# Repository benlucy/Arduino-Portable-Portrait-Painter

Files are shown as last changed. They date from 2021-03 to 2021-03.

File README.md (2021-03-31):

# Arduino-Portable-Portrait-Painter
Code to run Arduino based portable portrait painter

Mechanical Build on Instructables.com (coming soon)

Working machine: https://www.youtube.com/watch?v=U5dt6qbI_Uw 

-------------------------------------------------------------------------------  
  
Compiling in Arduino IDE:  
  
1. Download all files
2. Copy "src/lib/LiveOV7670Library" and "src/lib/Adafruit_GFX_Library" to Arduino "libraries" folder (If you already have "Adafruit_GFX_Library" then you don't have to copy that)
3. Open "src/LiveOV7670/LiveOV7670.ino" in Arduino IDE
4. Select Tools->Board->Arduino/Genuino Mega or Mega 2560
5. Select Tools->Processor->ATmega2560 (Mega 2560)
  
-------------------------------------------------------------------------------

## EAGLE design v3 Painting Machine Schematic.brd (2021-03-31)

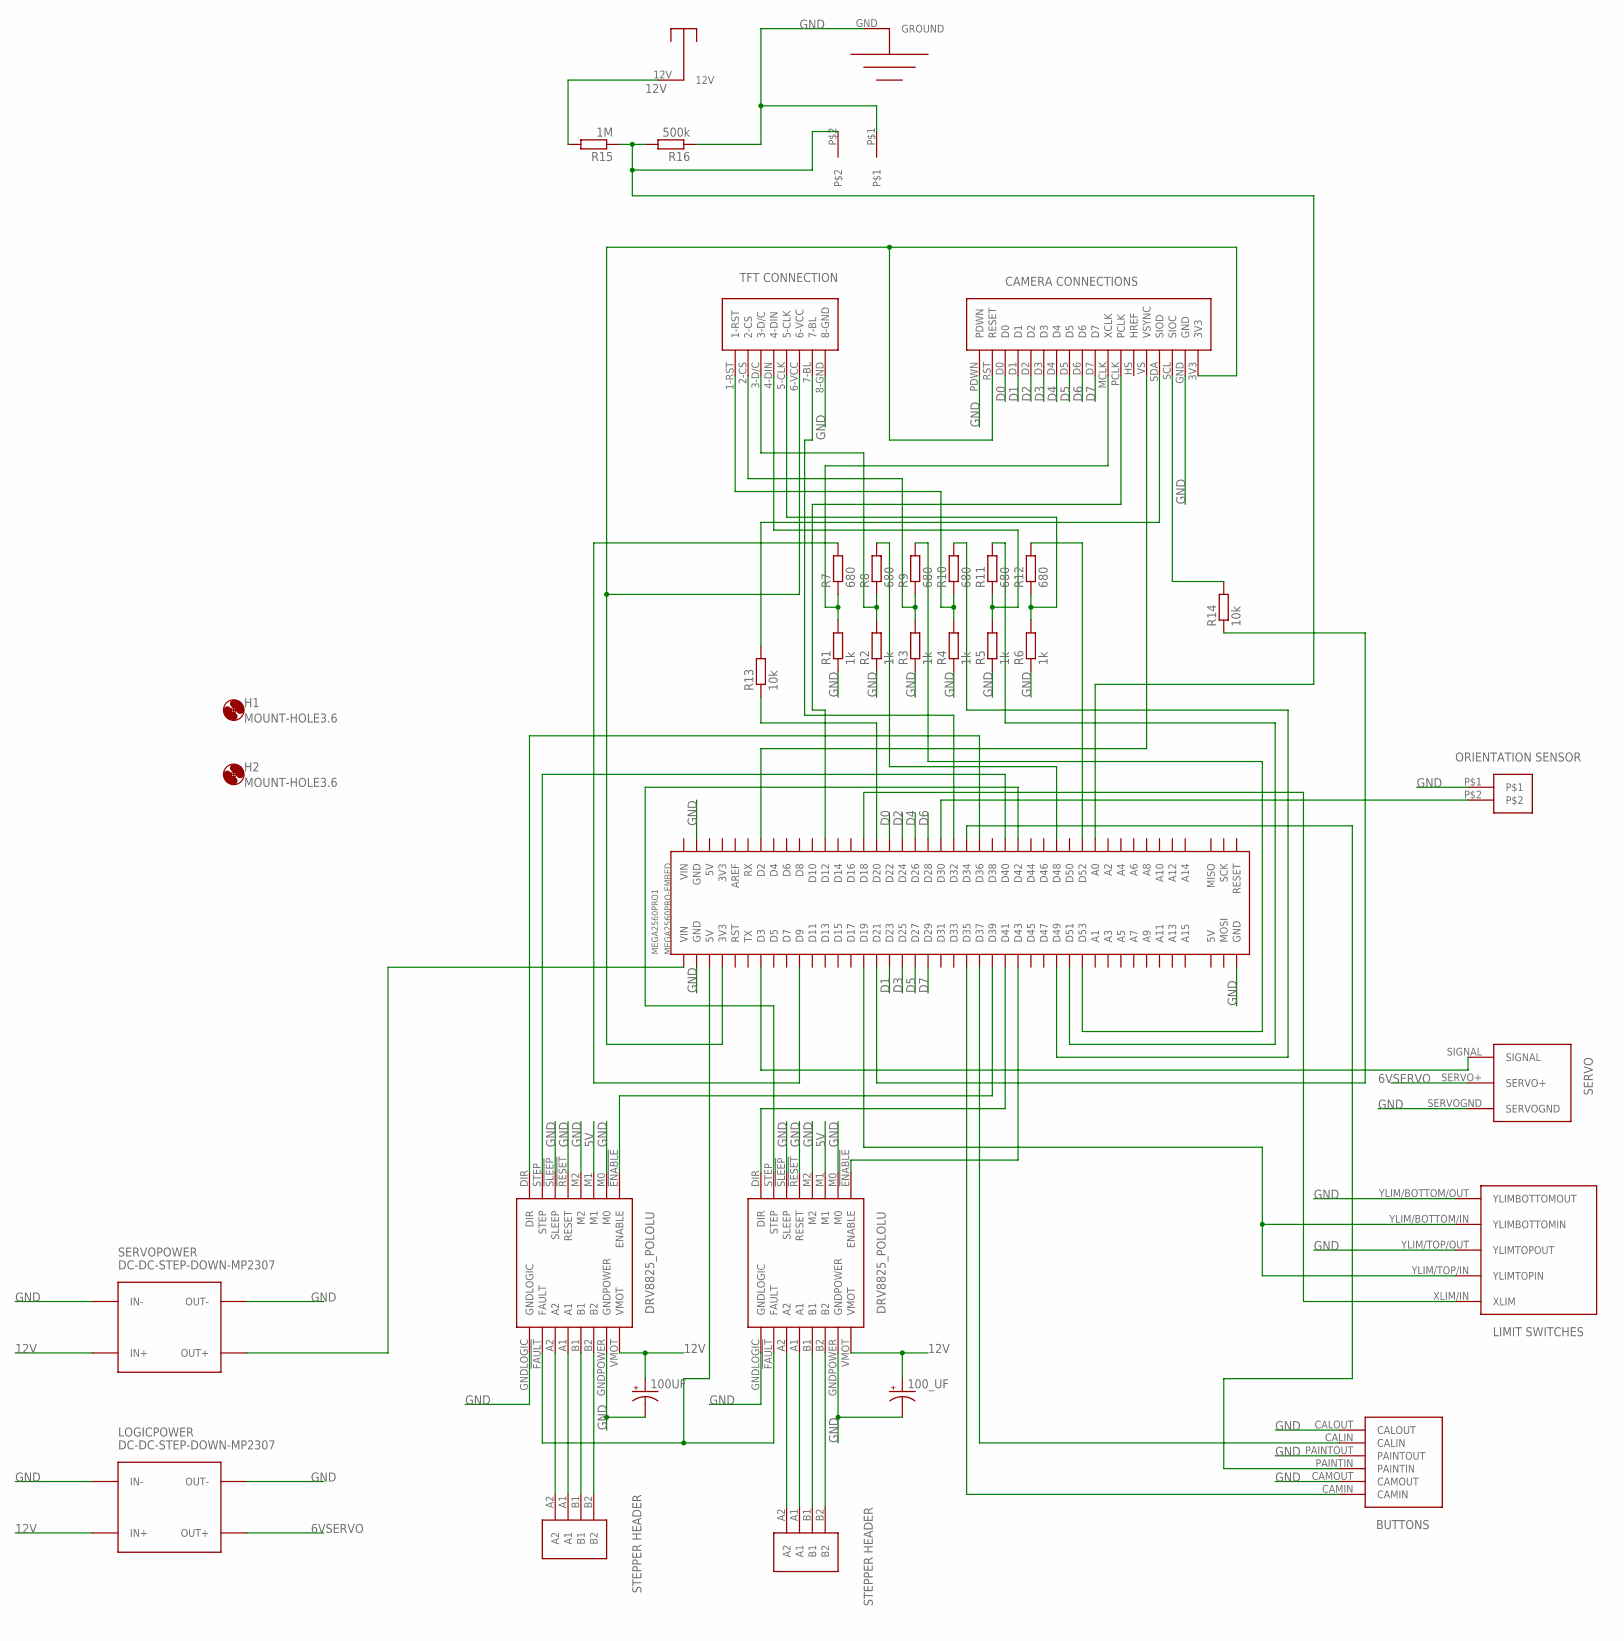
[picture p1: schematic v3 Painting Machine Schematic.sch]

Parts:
100UF, 100_UF: CPOL-USB45181B; B45181B
H1, H2: MOUNT-HOLE3.6; 3,6
LOGICPOWER: DC-DC-STEP-DOWN-MP2307
MEGA2560PRO1: MEGA2560PRO-EMBED
R1, R2, R3, R4, R5, R6: 1k; 0207/7
R7, R8, R9, R10, R11, R12: 680; 0207/7
R13, R14: 10k; 0207/7
R15: 1M; 0207/7
R16: 500k; 0207/7
SERVOPOWER: DC-DC-STEP-DOWN-MP2307
U$1, U$2: DRV8825_POLOLU_CARRIER; DRV8825_POLOLU
U$4: TFT/CONNECTIONS; TFTCONNECTIONS
U$5: OV7670CONNECTIONS; CAMERACONNECTIONS
U$6: ORIENTATIONSENSOR
U$7: 12V; VCC
U$8: GROUND
U$9, U$10: STEPPER_HEADER
U$11: SERVO
U$12: LIMITSWITCHES
U$13: BUTTONS; INPUTBUTTONS
U$14: CERAMICCAPACITOR

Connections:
5V: U$1.M1, U$2.M1
6VSERVO: LOGICPOWER.OUT+, U$11.SERVO+
12V: 100UF.+, 100_UF.+, LOGICPOWER.IN+, R15.2, SERVOPOWER.IN+, U$1.VMOT, U$2.VMOT, U$7.12V
D0: MEGA2560PRO1.D22, U$5.D0
D1: MEGA2560PRO1.D23, U$5.D1
D2: MEGA2560PRO1.D24, U$5.D2
D3: MEGA2560PRO1.D25, U$5.D3
D4: MEGA2560PRO1.D26, U$5.D4
D5: MEGA2560PRO1.D27, U$5.D5
D6: MEGA2560PRO1.D28, U$5.D6
D7: MEGA2560PRO1.D29, U$5.D7
GND: 100UF.-, 100_UF.-, LOGICPOWER.IN-, LOGICPOWER.OUT-, MEGA2560PRO1.GND@1 (GND), MEGA2560PRO1.GND@2 (GND), MEGA2560PRO1.GND@3 (GND), R1.1, R2.1, R3.1, R4.1, R5.1, R6.1, R16.1, SERVOPOWER.IN-, SERVOPOWER.OUT-, U$1.!RESET (RESET), U$1.!SLEEP (SLEEP), U$1.GNDLOGIC, U$1.GNDPOWER, U$1.M0, U$1.M2, U$2.!RESET (RESET), U$2.!SLEEP (SLEEP), U$2.GNDLOGIC, U$2.GNDPOWER, U$2.M0, U$2.M2, U$4.8-GND, U$5.GND, U$5.PDWN, U$6.P$1, U$8.GND, U$11.SERVOGND, U$12.YLIM/BOTTOM/OUT (YLIMBOTTOMOUT), U$12.YLIM/TOP/OUT (YLIMTOPOUT), U$13.CALOUT, U$13.CAMOUT, U$13.PAINTOUT, U$14.P$1
unnamed: U$2.A2, U$9.A2
unnamed: U$2.A1, U$9.A1
unnamed: U$2.B1, U$9.B1
unnamed: U$2.B2, U$9.B2
unnamed: U$1.A2, U$10.A2
unnamed: U$1.A1, U$10.A1
unnamed: U$1.B1, U$10.B1
unnamed: U$1.B2, U$10.B2
unnamed: MEGA2560PRO1.D9, R7.2
unnamed: MEGA2560PRO1.D48, R8.2
unnamed: MEGA2560PRO1.D53, R9.2
unnamed: MEGA2560PRO1.D49, R10.2
unnamed: R5.2, R11.1, U$4.4-DIN
unnamed: R6.2, R12.1, U$4.5-CLK
unnamed: MEGA2560PRO1.D12, U$5.PCLK
unnamed: MEGA2560PRO1.D52, R12.2
unnamed: MEGA2560PRO1.D51, R11.2
unnamed: R4.2, R10.1, U$4.1-RST
unnamed: R3.2, R9.1, U$4.2-CS
unnamed: R2.2, R8.1, U$4.3-D/C
unnamed: MEGA2560PRO1.D20, R13.1
unnamed: R1.2, R7.1, U$5.MCLK (XCLK)
unnamed: R13.2, U$5.SDA (SIOD)
unnamed: MEGA2560PRO1.D21, R14.1
unnamed: R14.2, U$5.SCL (SIOC)
unnamed: MEGA2560PRO1.3V3@1 (3V3), U$4.6-VCC, U$5.3V3, U$5.RST (RESET)
unnamed: MEGA2560PRO1.D2, U$5.VS (VSYNC)
unnamed: MEGA2560PRO1.D3, U$11.SIGNAL
unnamed: MEGA2560PRO1.D30, U$6.P$2
unnamed: MEGA2560PRO1.D19, U$12.YLIM/BOTTOM/IN (YLIMBOTTOMIN), U$12.YLIM/TOP/IN (YLIMTOPIN)
unnamed: MEGA2560PRO1.D18, U$12.XLIM/IN (XLIM)
unnamed: MEGA2560PRO1.D35, U$13.CAMIN
unnamed: MEGA2560PRO1.D37, U$13.CALIN
unnamed: MEGA2560PRO1.D34, U$13.PAINTIN
unnamed: MEGA2560PRO1.D41, U$1.DIR
unnamed: MEGA2560PRO1.D43, U$1.!ENABLE (ENABLE)
unnamed: MEGA2560PRO1.D39, U$2.!ENABLE (ENABLE)
unnamed: MEGA2560PRO1.D42, U$1.STEP
unnamed: MEGA2560PRO1.D40, U$2.STEP
unnamed: MEGA2560PRO1.D36, U$2.DIR
unnamed: MEGA2560PRO1.5V@1 (5V), U$1.!FAULT (FAULT), U$2.!FAULT (FAULT)
unnamed: MEGA2560PRO1.D32, U$4.7-BL
unnamed: MEGA2560PRO1.A0, R15.1, R16.2, U$14.P$2
VIN: MEGA2560PRO1.VIN@1 (VIN), SERVOPOWER.OUT+

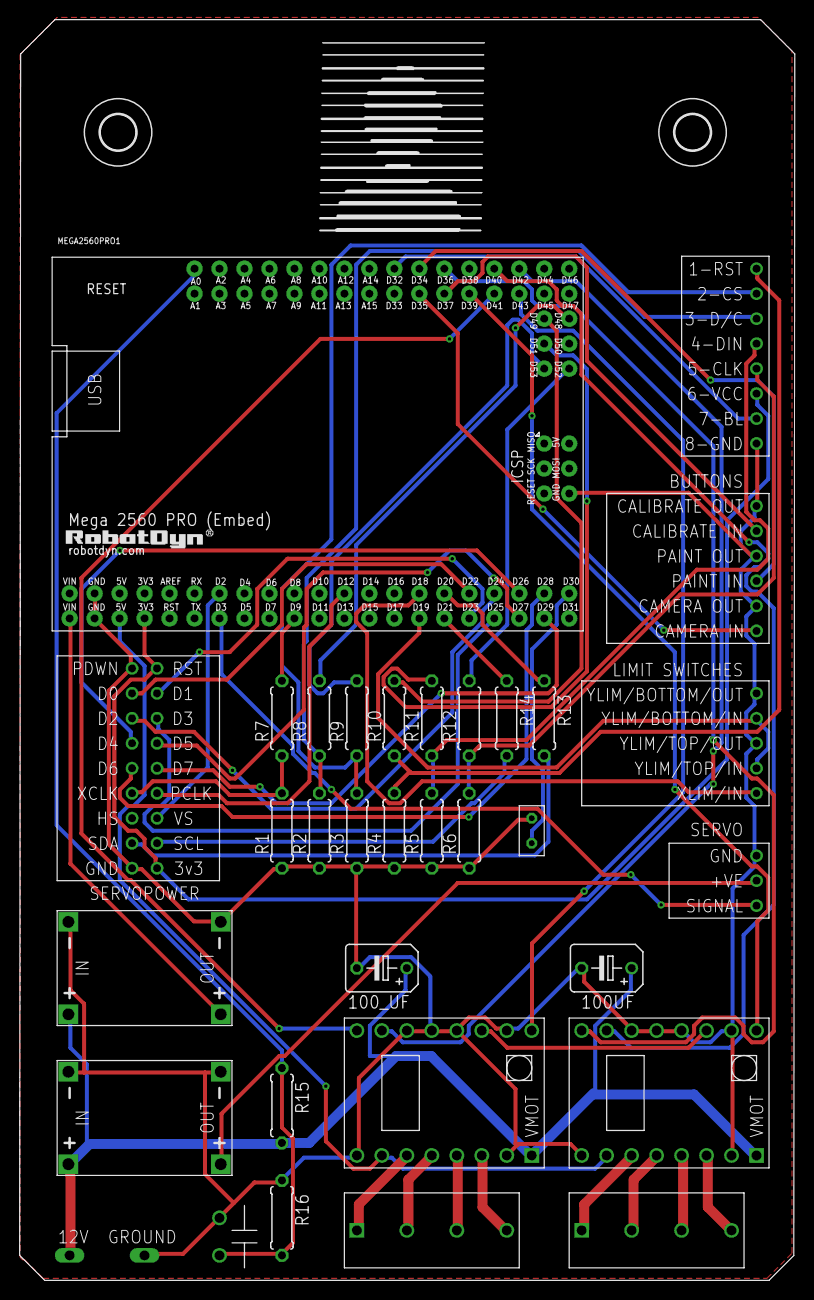
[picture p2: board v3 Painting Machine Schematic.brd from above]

Board: 2 copper layers, 78.8 x 128.2 mm, 36 parts (0 on the bottom side), 56 nets.

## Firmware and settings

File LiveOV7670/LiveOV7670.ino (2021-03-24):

//This code originally created by Indrek Luuk to display OV7670 video on a TFT screen.
//Modified by @SouravSh25 on 22.09.2020 to include a readGRAM  function, to read pixel data from the screen.
//Modified by Ben Lucy, to control a portable portait painting machine 18/12/2020.
//Code in this tab written by Ben Lucy, very minor edits have been made to the other tabs of Indrek's code e.g. edited variables to mirror the image.

// change setup.h to switch between buffered and pixel-by-pixel processing
#include "setup.h"
#include "Adafruit_ST7735_mod.h"
#include "readGRAM.h"
extern Adafruit_ST7735_mod tft;

#include <AccelStepper.h>
#include <Servo.h>


//declare all arduino pins inputs outputs

//TMC2208 stepper motor driver pins
#define RightStepperSTEP 40
#define RightStepperDIR 36
#define RightStepperENABLE 39

#define LeftStepperSTEP 42
#define LeftStepperDIR 41
#define LeftStepperENABLE 43

//limit switch inputs
#define Xlim 18
#define Ylim 19

//buttons
#define CalibrateButton 37
#define PaintButton 34
#define CameraButton 35

//other
#define ServoSignalPin 3
#define BatteryMonitor A0
#define OrientationSensor 30
#define BackLight 32


//define global variables
#define ZeroingSpeed 600
#define ServoMinHeight 158
#define ServoMaxHeight 30
#define ServoStartPosition 94
#define MinInterval 210 //(large = lower max speed. Too fast affects acceleration (crudely coded acc), causing skipped steps)
#define IntervalChange 100 //larger = faster acceleration which may cause skipped steps
int StepsTotal;
unsigned int CurrentTime;
unsigned int SavedTime;
int interval = MinInterval;
int TargetInterval = interval;
unsigned long previousMicros = 0;
byte StepPins = 0;
int MinContactHeight;
int MaxBrushPress = 22;
float ServoPos = 90;
int RowCounter = 0;
bool RunCamera = true;
float BrushArray[165];
float PixelValueFrequency[256];
float PixelValueCumulativeFrequency[256];
float PixelLookUpTable[256];
extern uint32_t GRAM_buffer[165]; //GRAM-buffer is declared in another tab, but I need it to have global scope to work here. 'Extern' makes it a data declaration, not a data definition.

//create instances for the AccelStepper class & Servo class:
AccelStepper LeftStepper = AccelStepper(1, LeftStepperSTEP, LeftStepperDIR);
AccelStepper RightStepper = AccelStepper(1, RightStepperSTEP, RightStepperDIR);
Servo BrushServo;

//conversion for brush change (degrees) to stepper interval (us) to travel at a speed that allows brush to change position within 1mm travel (1 pixel). Calculated via: 1000000(convert units to us)/ 25(no.steps)*300(deg/sec servo speed)*brush change(deg). Or: 1000000/(25*300*DegChange). Or: 66.7* DegChange

//if brush changes by 0 degree between one pixel and the next, stepper interval should be MinIntervalus (max speed). 3deg = 200us.
//interval is time between step pin changing state, so one step takes 2 intervals
//(1deg/2deg/3deg...etc
//{MinInterval, MinInterval, MinInterval, 200, 267, 333, 400, 467, 533, 600, 667, 733, 800, 867, 933, 1000, 1067, 1135, 1200, 1267, 1353, 1400, 1467};


void setup() {

  BrushServo.attach(ServoSignalPin);
  BrushServo.write(ServoPos);
  LeftStepper.setMaxSpeed(4000); //15000
  LeftStepper.setAcceleration(100000);
  BrushServo.attach(ServoSignalPin);
  BrushServo.write(ServoPos);
  RightStepper.setMaxSpeed(4000);
  RightStepper.setAcceleration(100000); //250000

  pinMode(BatteryMonitor, INPUT);
  pinMode(OrientationSensor, INPUT);


  pinMode(Xlim, INPUT_PULLUP);
  pinMode(Ylim, INPUT_PULLUP);

  pinMode(CalibrateButton, INPUT_PULLUP);
  pinMode(PaintButton, INPUT_PULLUP);
  pinMode(CameraButton, INPUT_PULLUP);

  pinMode(RightStepperENABLE, OUTPUT);
  pinMode(LeftStepperENABLE, OUTPUT);

  digitalWrite(LeftStepperENABLE, 1);
  digitalWrite(RightStepperENABLE, 1);
  
  BrushServo.detach();
  initializeScreenAndCamera();
  //  Serial.begin(9600);

  TIMSK0 = 0;



  //display battery voltage on start-up
  //fill screen to show battery charge condition
  digitalWrite(BackLight, 1);
  switch (analogRead(BatteryMonitor)) {
    case 0 ... 749:                       // <11.0V
      tft.fillScreen(ST7735_RED);
      break;
    case 750 ... 790:                     // 11.0 - 11.6V
      tft.fillScreen(ST7735_YELLOW);
      break;
    case 791 ... 1023:                    // >11.6V
      tft.fillScreen(ST7735_GREEN);
      break;
  }
  TIMSK0 = 1;
  delay(1000);
  tft.fillScreen(ST7735_BLACK);
  TIMSK0 = 0;

}

void loop() {

  tft.setRotation(2); //sets the screen the right way up. The values in Indrek's code have been edited so that the image shown is mirrored.

  //If CameraButton is pressed, start or stop the camera.
  if (RunCamera == true) processFrame(); // runs camera

  if (digitalRead(CameraButton) == LOW) {
    if (RunCamera == true) {
      RunCamera = false;                        //freezes camera/screen
      TIMSK0 = 1;                               //enable timer0 which enables delay() function (and millis function for elsewhere in the code).
      delay(500);                               //button debounce / long press prevention
    }
    else {
      RunCamera = true;                         //resumes camera
      delay(500);                               //button debounce / long press prevention
      TIMSK0 = 0;                               //disables timer0 which removes artifacts from the screen
    }
  }



  //If calibrate button is pressed:
  //Axes are zeroed.
  //Gantry starts drawing lines while the brush moves lower and lower.
  //When the brush makes contact with the page and starts drawing a line, the user should press calibrate again.
  //The system will save the MinimumContactHeight of the servo (servo position when calibrate was pressed 2nd time).
  //The system will stop drawing lines and re-zero the axes.

  if (digitalRead(CalibrateButton) == LOW) {
    digitalWrite(LeftStepperENABLE, 0);
    digitalWrite(RightStepperENABLE, 0);
    RunCamera = false;
    TIMSK0 = 1;
    BrushServo.attach(ServoSignalPin);
    BrushServo.write(ServoPos - 25);
    ZeroAxes();
    CalibrateRoutine();
    BrushServo.detach();
    digitalWrite(LeftStepperENABLE, 1);
    digitalWrite(RightStepperENABLE, 1);
  }


  //If paint button is pressed:
  //Axes are zeroed
  //Brush moves up to start position
  // (a) Image processing happens
  // (b) 128 pixels are read from the screen
  // (c) 128 pixels are painted and the brush moves to the next row position
  // a & b repeat for 80 rows
  //the brush is lifted
  //the axes are zeroed.


  if (digitalRead(PaintButton) == LOW) {  //paint the image currently frozen on the screen.
    digitalWrite(LeftStepperENABLE, 0);
    digitalWrite(RightStepperENABLE, 0);

    RunCamera = false;
    TIMSK0 = 1;
    BrushServo.attach(ServoSignalPin);

    ZeroAxes();

    //move up 1375 steps (55mm)
    LeftStepper.move(1375);
    RightStepper.move(-1375);
    while (LeftStepper.currentPosition() != 1375) {
      LeftStepper.run();
      RightStepper.run();
    }

    ImageProcessing();

    RowCounter = 3;  //first few rows of pixels might be nothing? Maybe they're not actual pixels and just exist in the screen register?? Maybe they are legit pixels but I can't bother to upload and verify.
    while (RowCounter < 160) {

      //read the screen GRAM
      initiate_readGRAM();
      readGRAM_Row(GRAM_buffer, RowCounter);


      //converts the pixel array into brush positions. //Using data-type 'byte' for PixelLookUpTable might shorten the pause before painting each line.
      for (int i = 0; i < 128; i++) {
        GRAM_buffer[i] = GRAM_buffer[i] << 16;                                    //GRAM_buffer contains 32bit numbers. The first 8x bits are zero. The next 3 bytes are similar (because RGB/greyscale). G has the most info because RGB565, so use G byte. Outputs number from 0-255 after <<16 & >>24.
        GRAM_buffer[i] = GRAM_buffer[i] >> 24;
        GRAM_buffer[i] = PixelLookUpTable[GRAM_buffer[i]]; //Am I getting away with putting float into long here??  ??  //Revises the pixels according to Histogram Equalisation. E.g. the 5th pixel has a value 106 (GRAM_buffer[5] == 106). The 106th element of the PixelLookUpTable is 122, so the fifth pixel is updated with this value (GRAM_buffer[5]=122).
        BrushArray[i] = (float)GRAM_buffer[i];                                    //cast to float array
        BrushArray[i] = MinContactHeight + MaxBrushPress - (BrushArray[i] * (MaxBrushPress / 255.0));    //Scales BrushArray into servo-range friendly values. Weird formula is because BrushArray seems to be inverted.
      }

      Paint128Pixels();
      ReadyForNextRow();
      RowCounter = RowCounter + 2;
    }
    BrushServo.write(ServoPos - 35);
    delay(250);
    ZeroAxes();
    BrushServo.detach();
    digitalWrite(LeftStepperENABLE, 1);
    digitalWrite(RightStepperENABLE, 1);
    initializeScreenAndCamera();
  }
}

//function to zero axes at the bottom left corner
void ZeroAxes() {

  while (digitalRead(Xlim) == HIGH) {
    LeftStepper.setSpeed(-1 * ZeroingSpeed);
    RightStepper.setSpeed(-1 * ZeroingSpeed);
    LeftStepper.runSpeed();
    RightStepper.runSpeed();
  }

  while (digitalRead(Ylim) == HIGH) {
    LeftStepper.setSpeed(-1 * ZeroingSpeed);
    RightStepper.setSpeed(ZeroingSpeed);
    LeftStepper.runSpeed();
    RightStepper.runSpeed();
  }

  LeftStepper.setCurrentPosition(0);
  RightStepper.setCurrentPosition(0);

  //moves 4mm right and 4mm up.
  while (LeftStepper.currentPosition() != 200)
  {
    LeftStepper.setSpeed(ZeroingSpeed);
    LeftStepper.runSpeed();
  }
  LeftStepper.setCurrentPosition(0);
  RightStepper.setCurrentPosition(0);

  //move the servomotor down a little to stop it making noise
  BrushServo.write(ServoPos + 1);
  delay(200);
  BrushServo.write(ServoPos + 1);
  delay(200);
  BrushServo.write(ServoPos + 1);
}

void CalibrateRoutine() {

  //run the stepper motors in an 80 line pattern
  int LinesDrawn = 0;
  int CalibrateState = 1;
  while (LinesDrawn != 80 && CalibrateState == 1) {

    BrushServo.write(ServoPos);

    //move right 128mm (3200 steps)
    LeftStepper.move(3200);
    RightStepper.move(3200);
    while (LeftStepper.distanceToGo() != 0 && digitalRead(CalibrateButton) == HIGH) {
      LeftStepper.run();
      RightStepper.run();
    }

    BrushServo.write(ServoPos - 35);

    //move up 2mm (50steps)
    LeftStepper.move(50);
    RightStepper.move(-50);
    while (LeftStepper.distanceToGo() != 0 && digitalRead(CalibrateButton) == HIGH) {
      LeftStepper.run();
      RightStepper.run();
    }

    //move left 130mm (3200)
    LeftStepper.move(-3200);
    RightStepper.move(-3200);
    while (LeftStepper.distanceToGo() != 0 && digitalRead(CalibrateButton) == HIGH) {
      LeftStepper.run();
      RightStepper.run();
    }

    if (digitalRead(CalibrateButton) == LOW) {
      CalibrateState = 2;
      MinContactHeight = ServoPos;
      ServoPos = 90;
      BrushServo.write(ServoPos - 25);
      delay(250);
      ZeroAxes();
    }

    LinesDrawn = LinesDrawn + 1;
    ServoPos = ServoPos + 1;

  }
}

void Paint128Pixels() {

  digitalWrite(LeftStepperDIR, 1);
  digitalWrite(RightStepperDIR, 1);

  StepsTotal = 0;
  previousMicros = 0;
  char CurrentPixel = 0;
  char PreviousPixel = 0;
  char BrushChange;
  char PixelStepsTotal = 0;
  long microsAfter;
  long microsBefore;

  while (StepsTotal < 6400) {                                             //64000 = half steps. 25 full steps is 1mm

    //************************************************
    //every pixel (50) check difference in brush position between current and next pixel in GRAM_buffer[]
    //update stepper interval variable according to brush movement distance

    if (PixelStepsTotal >= 50) {                                           //executes every pixel (50 half-steps). (Used to use modulo for this but strange things happened)
      PixelStepsTotal = 0;
      PreviousPixel = CurrentPixel;                                           //indicates which pixel we were on (0 - 127)
      CurrentPixel = CurrentPixel + 1;                                        //indicates which pixel we are currently on (0 - 127)
      BrushChange = BrushArray[PreviousPixel] - BrushArray[CurrentPixel];       //difference between current and previous brush position is the distance the brush must move (in degrees)
      BrushChange = abs(BrushChange);
      if (BrushChange >= 3) TargetInterval = 67 * BrushChange;                      //66.7 converts servo position degree change to an interval controlling the speed the steppers should be going to allow the brush to change position within the width of 1 pixel. Line ~71 comment
      else TargetInterval = MinInterval;
      BrushServo.write(BrushArray[CurrentPixel]);

      if (digitalRead(PaintButton) == LOW) {   //Press paint button again to cancel painting
        StepsTotal = 6401;                     //Exits while loop
        RowCounter = 161;                      //Exits back to loop()
        ServoPos = 90;
        BrushServo.write(ServoPos - 35);
        delay(250);
        ZeroAxes();
        BrushServo.detach();
        digitalWrite(LeftStepperENABLE, 1);
        digitalWrite(RightStepperENABLE, 1);
      }
    }

    //***********************************************
    //Crude way of including acceleration. Acceleration will be non-linear
    //Large changes in interval will cause skipped steps. This code ensures that changes will be 100 max.
    //Will mean that brush may not complete movement during 1mm pixel, but 300deg/sec is quite conservative & it's an arbitrary target anyway.

    if (interval < TargetInterval) {
      if ((TargetInterval - interval) < IntervalChange) interval = interval + (TargetInterval - interval);
      else interval = interval + IntervalChange;
    }

    if (interval > TargetInterval) {
      if ((interval - TargetInterval) < IntervalChange) interval = interval - (interval - TargetInterval);
      else interval = interval - IntervalChange;
    }
    //***********************************************

    //***********************************************
    //every 'interval' if the step pins are high turn them low and vice-versa. This constitutes half a step cycle.

    unsigned long currentMicros = micros();

    if (currentMicros - previousMicros >= interval) {

      previousMicros = currentMicros;


      if (StepPins == 0) {
        PORTL |= 0b10000000;         //makes pin 42 high (left step pin)
        PORTG |= 0b00000010;         //makes pin 40 high (right step pin)
        StepPins = 1;
      } else {
        PORTL &= 0b01111111;         //makes pin 42 low
        PORTG &= 0b11111101;         //makes pin 40 low
        StepPins = 0;
      }
      StepsTotal = StepsTotal + 1;
      PixelStepsTotal = PixelStepsTotal + 1;

    }
    //***********************************************
  }
}

void ImageProcessing() {                      //increase contrast of image according to histogram equalisation technique.

  initiate_readGRAM();
  for (byte a = 0; a < 160; a = a + 2) {      //for 80 rows of pixels on the screen,
    readGRAM_Row(GRAM_buffer, a);             //read the current row of 128 pixels (outputs GRAM_buffer which is a long array of 128 pixels (uint_32))

    for (byte b = 0; b < 128; b++) {          //convert the row of pixels so that we only keep the Green byte.
      GRAM_buffer[b] = GRAM_buffer[b] << 16;
      GRAM_buffer[b] = GRAM_buffer[b] >> 24;
    }

    for (byte c = 0; c < 128; c++) {                                                   //count the frequency of pixel values in the row, for all 80 rows.
      PixelValueFrequency[GRAM_buffer[c]] = PixelValueFrequency[GRAM_buffer[c]] + 1;   //e.g. if GRAM_buffer[c] = 42, then access the 42nd element of PixelValueFrequency, and add one to the count.
    }
  }

  for (int f = 0; f < 256; f++) {                                                      //once the frequency of all pixel values on the screen has been counted (80rows x 128 columns = 10,240 pixels), calculate cumulative frequency:
    if (f == 0 || f == 1) {    //don't want to include 100% black pixels in the calculation, as a relatively large amount of the pixels at the edges of the screen might default black and not updated by the camera code, which will skew the histogram.
      PixelValueCumulativeFrequency[f] = 0;
    }
    else {
      PixelValueCumulativeFrequency[f] = PixelValueFrequency[f] + PixelValueCumulativeFrequency[f - 1];
    }
  }

  //need to account for pixels that are 0 or 255. (eliminate from count)
  //in order to do this, we need to know the total number of pixels counted which fall between the range 1-254
  float CumulativePixels = 0.0;
  for (int d = 1; d < 252; d++) {
    CumulativePixels = CumulativePixels + PixelValueFrequency[d];
  }

  //now that the pixels for the entire image have been counted, produce a look-up table to convert the image according to the Histogram Equalisation method.
  for (int e = 1; e < 252; e++) {
    PixelLookUpTable[e] = (PixelValueCumulativeFrequency[e] / CumulativePixels) * 255;
  }
  PixelLookUpTable[0] = 0;
  PixelLookUpTable[252] = 255;
  PixelLookUpTable[253] = 255;
  PixelLookUpTable[254] = 255;
  PixelLookUpTable[255] = 255;        //because it's 565 colour compression, there are actually only 6 bits & therefore 64 levels of black-grey-white (even though readGRAM_row() gives 3x 8bits). Could have accounted for this and made the code slightly more efficient. Instead I bodged & patched.
}

void ReadyForNextRow() {
  //raises brush
  //moves brush to beginning of next row
  //lowers brush

  //raises brush:
  BrushServo.write(MinContactHeight - 25 );

  //moves brush to beginning of next row:
  //move up 2mm (50steps)
  LeftStepper.move(50);
  RightStepper.move(-50);
  while (LeftStepper.distanceToGo() != 0) {
    LeftStepper.run();
    RightStepper.run();
  }

  //move left 130mm (3200)
  LeftStepper.move(-3200);
  RightStepper.move(-3200);
  while (LeftStepper.distanceToGo() != 0) {
    LeftStepper.run();
    RightStepper.run();
  }

  //lowers brush:
  BrushServo.write(MinContactHeight);
}

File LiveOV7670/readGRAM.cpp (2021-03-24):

// see if 4-line mode can read anything

#include "readGRAM.h"
#include <SPI.h>

#if defined(__AVR_ATmega1280__) || defined(__AVR_ATmega2560__)
#define TFT_DC  (48)     //DC=7 for HX8347
#define TFT_RESET (49)   //Backlight on HX8347
#define SS (53)
#define SCK (52)
#define MOSI (51)
#else
#define TFT_DC  (8)     //DC=7 for HX8347
#define TFT_RESET (10)   //Backlight on HX8347
#define SS (9)
#define SCK (13)
#define MOSI (11)
#endif

uint32_t GRAM_buffer[165];

void SPIwrite(uint8_t data)
{
  pinMode(MOSI, OUTPUT);
  for (int i = 0; i < 8; i++)
  {
    digitalWrite(MOSI, (data & 0x80) != 0);
    digitalWrite(SCK, HIGH);
    digitalWrite(SCK, LOW);
    data <<= 1;
  }
}

uint8_t readSPI()
{
  uint8_t data = 0;
  pinMode(MOSI, INPUT_PULLUP);;
  for (int i = 0; i < 8; i++)
  {
    data <<= 1;
    if (digitalRead(MOSI)) data |= 1;;
    digitalWrite(SCK, HIGH);
    digitalWrite(SCK, LOW);

  }
  return data;
}

void writeData(uint8_t Data)
{
  digitalWrite(SS, LOW);
  digitalWrite(TFT_DC, HIGH);
  SPIwrite(Data);
  digitalWrite(SS, HIGH);
}

void writeCmd(uint8_t cmd)
{
  digitalWrite(SS, LOW);
  digitalWrite(TFT_DC, LOW);
  SPIwrite(cmd);
  digitalWrite(SS, HIGH);
}

uint8_t readData()
{
  uint8_t data = 0;
  digitalWrite(SS, LOW);
  digitalWrite(TFT_DC, HIGH);
  data = readSPI();
  digitalWrite(SS, HIGH);
  return data;
}

void setXY(uint8_t x0, uint8_t x1, uint8_t y0, uint8_t y1)
{
  writeCmd(0x2A);
  writeData(0x00);
  writeData(x0);
  writeData(0x00);
  writeData(x1);

  writeCmd(0x2B);
  writeData(0x00);
  writeData(y0);
  writeData(0x00);
  writeData(y1);
}

void readID()
{
  Serial.print("Read ID cmd: 0x");
  digitalWrite(SS, LOW);
  digitalWrite(TFT_DC, LOW);
  SPIwrite(0x04);

  digitalWrite(TFT_DC, HIGH);
  digitalWrite(SCK, HIGH);
  digitalWrite(SCK, LOW);
  for (int i = 0; i < 3; i++)
  {
    Serial.print(readSPI(), HEX);
  }
  digitalWrite(SS, HIGH);
  Serial.println("...End ");
}

void readGRAM_Row(uint32_t *dataBuff, uint8_t Row_number)
{
  uint8_t tempValue = 0;
  setXY(0, 128, Row_number, Row_number + 1);
  // Serial.print("Read GRAM Row: ");
  digitalWrite(SS, LOW);
  digitalWrite(TFT_DC, LOW);
  SPIwrite(0x2E);
  digitalWrite(TFT_DC, HIGH);
  readSPI();  // Dummy 1 byte read
  for (int i = 0; i < 128; i++)
  {
    dataBuff[i] = 0x00000000;
  //     Serial.print("0x");
    for (int j = 0; j < 3; j++)
    {
      dataBuff[i] = (dataBuff[i] << 8);
      tempValue = (readSPI() << 1);
      dataBuff[i] |= tempValue;
  //        if(tempValue < 0x10) { Serial.print("0"); }
  //        Serial.print(tempValue, HEX);
    }
   //  Serial.print(", ");
 //       if((i%8) == 0)
 //    {
 //     Serial.println("");
//    }
  }
  digitalWrite(SS, HIGH);
//    Serial.println("...End ");
}

void readGRAM_Column(uint32_t *dataBuff, uint8_t Column_number)
{
  uint8_t tempValue = 0;
  setXY(Column_number, Column_number + 1, 0, 160);
  Serial.print("Read GRAM Column: ");
  digitalWrite(SS, LOW);
  digitalWrite(TFT_DC, LOW);
  SPIwrite(0x2E);
  digitalWrite(TFT_DC, HIGH);
  readSPI();  // Dummy 1 byte read
  for (int i = 0; i < 160; i++)
  {
    dataBuff[i] = 0x00000000;
    //  Serial.print("0x");
    for (int j = 0; j < 3; j++)
    {
      dataBuff[i] = (dataBuff[i] << 8);
      tempValue = (readSPI() << 1);
      dataBuff[i] |= tempValue;
      if (tempValue < 0x10) {
        Serial.print("0");
      }
      Serial.print(tempValue);
    }
    Serial.print(", ");
    if ((i % 8) == 0)
    {
      Serial.println("");
    }
  }
  digitalWrite(SS, HIGH);
  Serial.println("...End ");
}

void FillRainbow()
{
  int Row = 0, Column = 0;
  uint32_t color = 0;
  uint8_t red = 0, green = 0, blue = 0;
  setXY(0, 128, 0, 160);
  writeCmd(0x2C);
  digitalWrite(SS, LOW);
  digitalWrite(TFT_DC, HIGH);

  Serial.println("Rainbow Screen Start");
  for (int Row = 0; Row < 160; Row++)
  {
    Serial.print(".");
    for (int Column = 0; Column < 128; Column++)
    {
      SPIwrite(red);
      SPIwrite(green);
      SPIwrite(blue);

      if ((Row == 0) || (Row == 1))
      {
        red += 0x02;
        green += 0x02;
        blue += 0x02;
      }
      else
      {
        red = Row * 2;
        green = Column * 2;
        blue = Row + Column;
      }
    }
  }
  digitalWrite(SS, HIGH);
  Serial.println("Rainbow Screen Ends.");
}


void fillscreen(uint8_t red, uint8_t green, uint8_t blue)
{
  setXY(0, 128, 0, 160);
  writeCmd(0x2C);
  digitalWrite(SS, LOW);
  digitalWrite(TFT_DC, HIGH);
  for (int i = 0; i < 20480; i++)
  {
    SPIwrite(red);
    SPIwrite(green);
    SPIwrite(blue);
  }
  digitalWrite(SS, HIGH);
  Serial.println("");
  Serial.print("Data Written on GRAM 0x");
  if (red < 0x10) {
    Serial.print("0");
  }
  Serial.print(red, HEX);
  if (green < 0x10) {
    Serial.print("0");
  }
  Serial.print(green, HEX);
  if (blue < 0x10) {
    Serial.print("0");
  }
  Serial.println(blue, HEX);
  Serial.println("");
}

void initiate_readGRAM()
{
  SPI.end();
  /*  Configure the PIN modes */
  digitalWrite(SS, HIGH);
  pinMode(SS, OUTPUT);
  pinMode(SCK, OUTPUT);
  pinMode(MOSI, OUTPUT);
  pinMode(MISO, INPUT_PULLUP);
  pinMode(TFT_DC, OUTPUT);
  digitalWrite(TFT_RESET, HIGH);
  pinMode(TFT_RESET, OUTPUT);

  writeCmd(0x01);            //Software Reset
  delay(100);

  writeCmd(0x11);            //Sleep Out
  delay(100);
  writeCmd(0x29);     // Dislay ON
  delay(100);
}

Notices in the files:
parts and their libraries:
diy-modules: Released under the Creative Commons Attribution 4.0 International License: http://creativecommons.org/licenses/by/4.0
